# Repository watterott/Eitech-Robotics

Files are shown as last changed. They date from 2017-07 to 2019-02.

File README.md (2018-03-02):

# Eitech Robotics
Eitech Robotics is an Microchip SAMW25 based open-source robotics board.

* [Microchip ATSAMW25](http://www.microchip.com/wwwproducts/en/ATSAMW25) Module (SAM D21 ARM Cortex-M0+ and WINC1500 WiFi/WLAN SoC)
* USB CDC+MSC Bootloader (Arduino compatible)
* 5V tolerant IOs, UART, SPI, I2C
* 2x Dual Full-Bridge Motor Drivers (Allegro Micro A3909, up to 1A per Phase)
* 5V Switching Regulator (up to 2A)

## Hardware and Software
* [Schematics/Layout](https://github.com/watterott/Eitech-Robotics/tree/master/hardware)
* [Board Support Package for Arduino IDE](https://github.com/watterott/Eitech-Robotics/tree/master/arduino#eitech-board-support-package)
* [Driver for Windows](https://github.com/watterott/Eitech-Robotics/raw/master/arduino/driver.zip)

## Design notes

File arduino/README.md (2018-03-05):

# Eitech Board Support Package
Board Support Package for [Arduino IDE v1.8+](https://www.arduino.cc/en/Main/Software).

## Installation

Add the following URL to the Arduino Boards Manager (*File->Preferences*):
```
https://github.com/watterott/Eitech-Robotics/raw/master/arduino/package_eitech_index.json
```
Then open the Arduino Boards Manager (*Tools->Boards->Boards Manager*) and install the 
**Arduino SAMD Boards** and **Eitech SAMD Boards**.

## Bootloader

The bootloader can be activated via the Arduino IDE or by doing two reset in 0.5s (double pressing reset switch).

When the bootloader is active then a new program can be loaded via the Arduino IDE and the serial port or via the mass storage device.
For the mass storage device just copy a new binary file (.bin) to the drive.

On Linux/Mac the dd command can be used to write the firmware: ```dd if=APP.BIN of=/media/ROBOTICS/APP.BIN conv=notrunc```

A binary file can be generated and exported in the Arduino IDE with *Sketch->Export compiled Binary* command.

## Known Issues

### Windows
Sometimes the driver for the USB Bootloader is not loaded correctly.
Check the driver state in the Device Manager, when the Bootloader is active (double press reset).
If you cannot install the driver on Windows 8 or higher then deactivate the [driver signature enforcement](https://learn.sparkfun.com/tutorials/disabling-driver-signature-on-windows-8/disabling-signed-driver-enforcement-on-windows-8).
* [Eitech Robotics Driver](https://github.com/watterott/Eitech-Robotics/raw/master/arduino/driver.zip)

### Linux
The Modem Manager detects the Serial Ports (e.g. the USB Bootloader) as a modem and therefore a blacklist rule is needed.
Run one of the commands - depending on your system:

```sudo nano /etc/udev/rules.d/77-mm-usb-device-blacklist.rules```

```sudo nano /lib/udev/rules.d/77-mm-usb-device-blacklist.rules```

and add the following lines to the file:
```
ATTRS{idVendor}=="1D50", ATTRS{idProduct}=="6110", ENV{ID_MM_DEVICE_IGNORE}="1"
ATTRS{idVendor}=="1D50", ATTRS{idProduct}=="6111", ENV{ID_MM_DEVICE_IGNORE}="1"
```

Reload udev rules:
```
sudo udevadm control --reload-rules
```

Or you can also remove the Modem Manager from your system with
```
sudo apt-get uninstall modemmanager
```

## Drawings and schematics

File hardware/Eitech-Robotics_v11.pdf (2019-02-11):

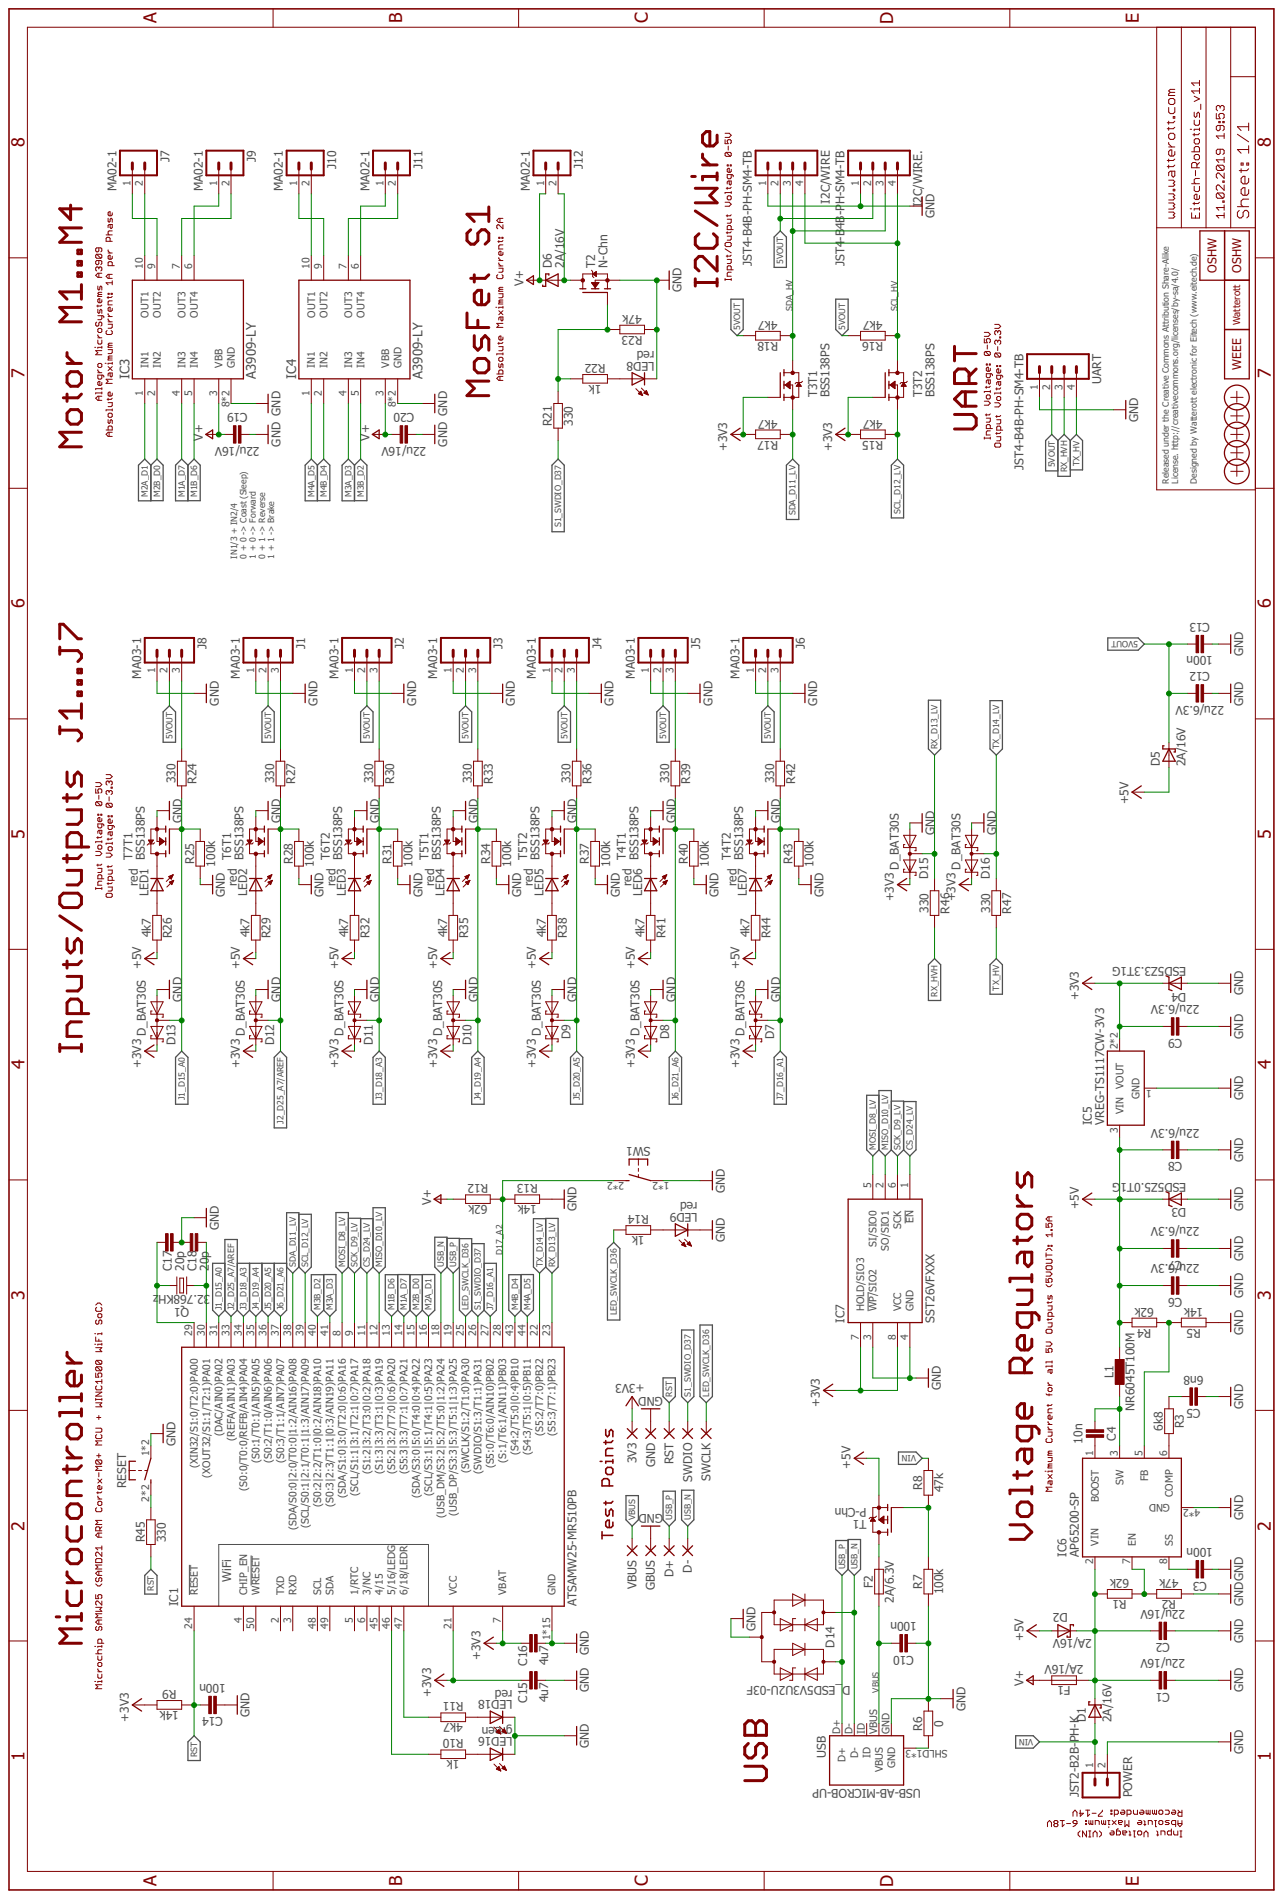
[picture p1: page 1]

Released under the Creative Commons Attribution Share-Alike

License. http://creativecommons.org/licenses/by-sa/4.0/ Designed by Watterott electronic for Eitech (www.eitech.de)

GND GND GND GND GND

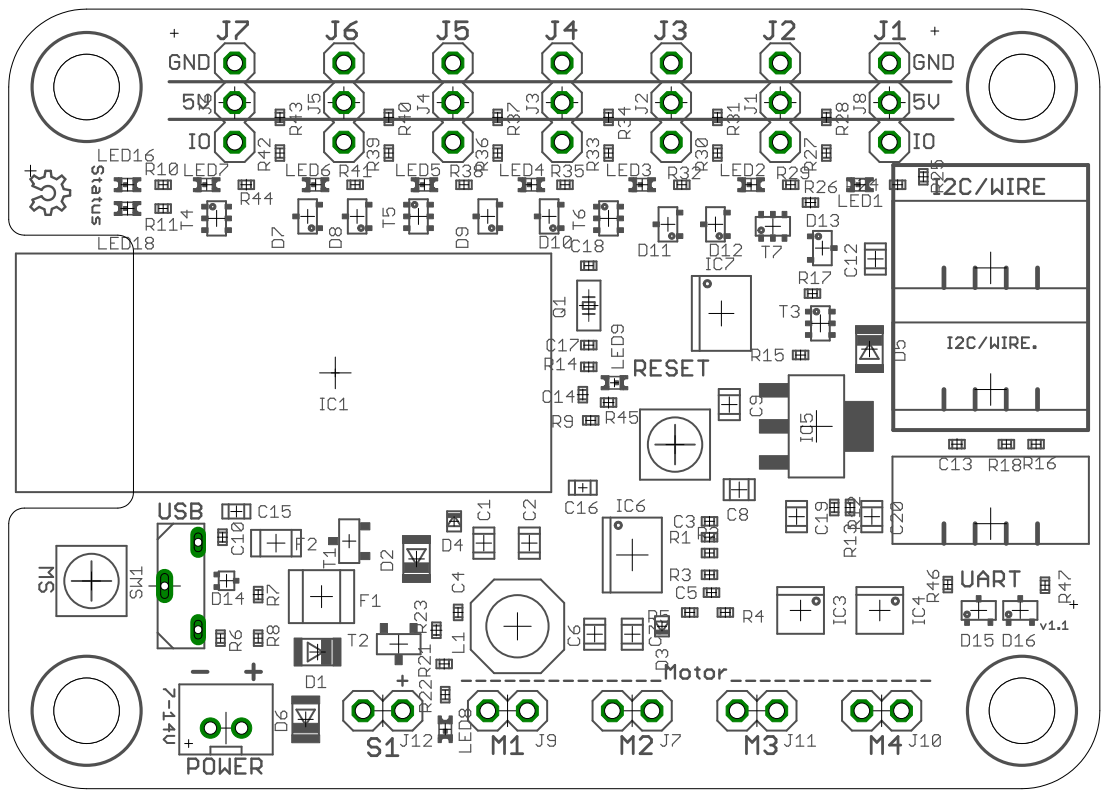
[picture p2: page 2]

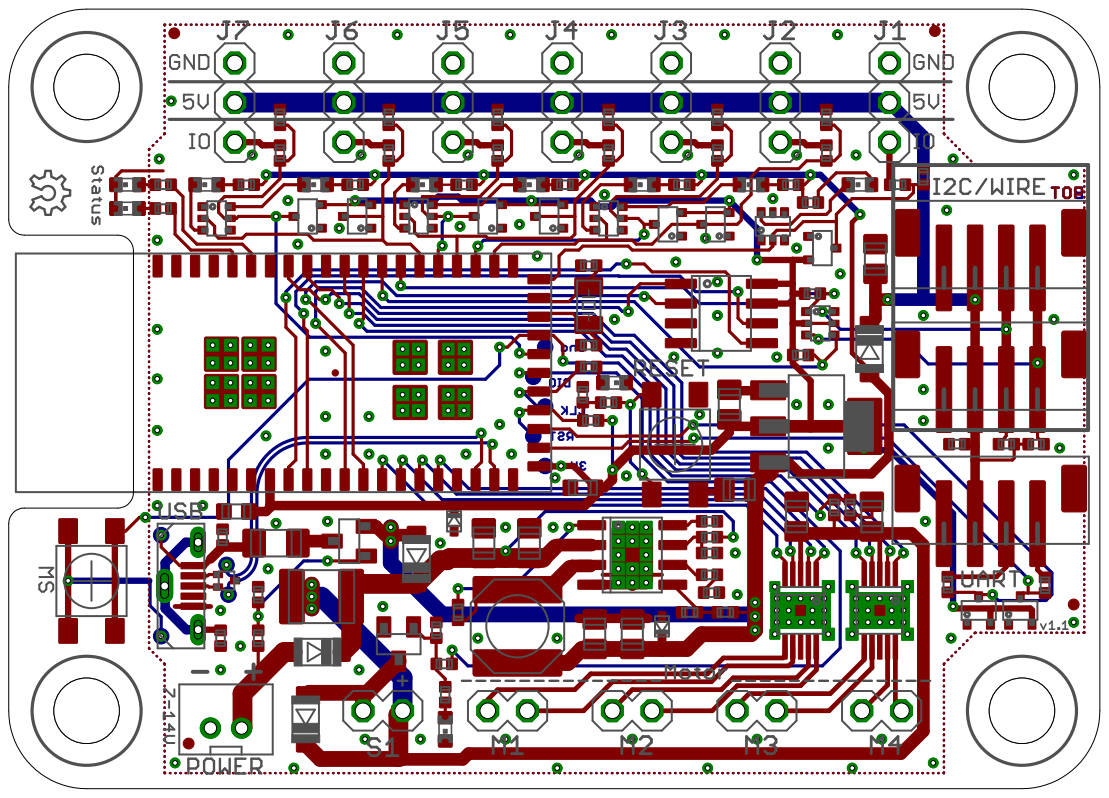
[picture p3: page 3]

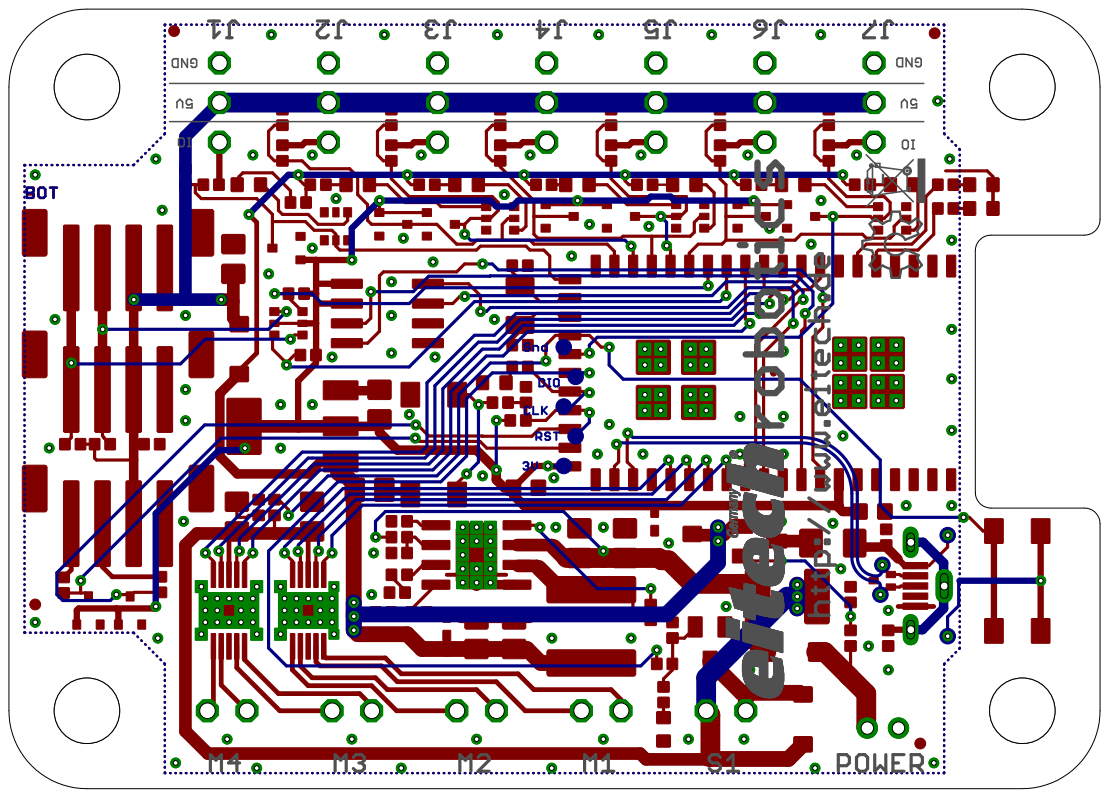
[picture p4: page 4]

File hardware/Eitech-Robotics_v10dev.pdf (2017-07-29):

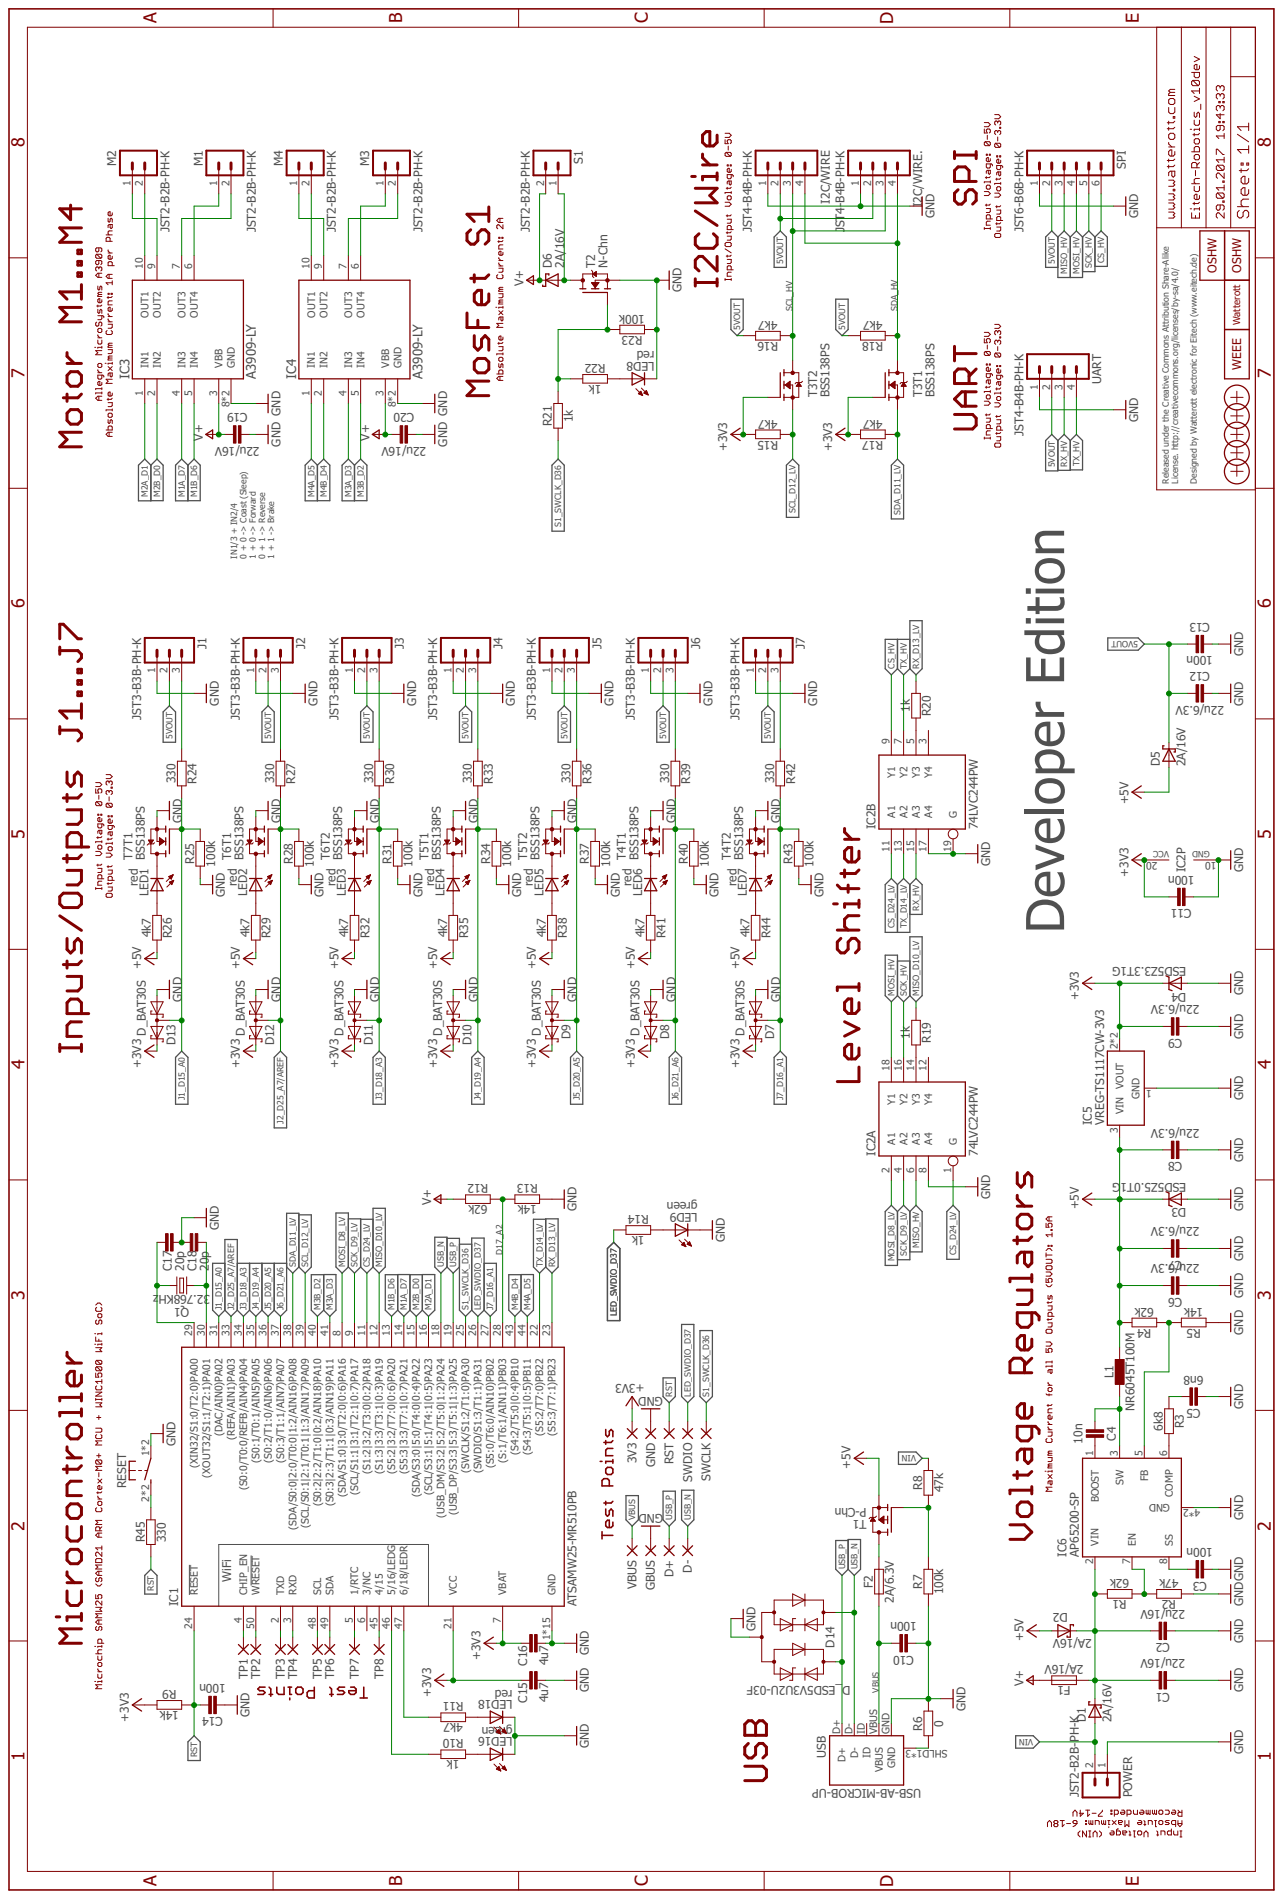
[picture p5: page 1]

License. ht p://creativecommons.org/licenses/by-sa/4.0/ Designed by Wat erot electronic for Eitech (www.eitech.de) D

Released under the Creative Commons At ribution Share-Alike

GND GND GND GND GND

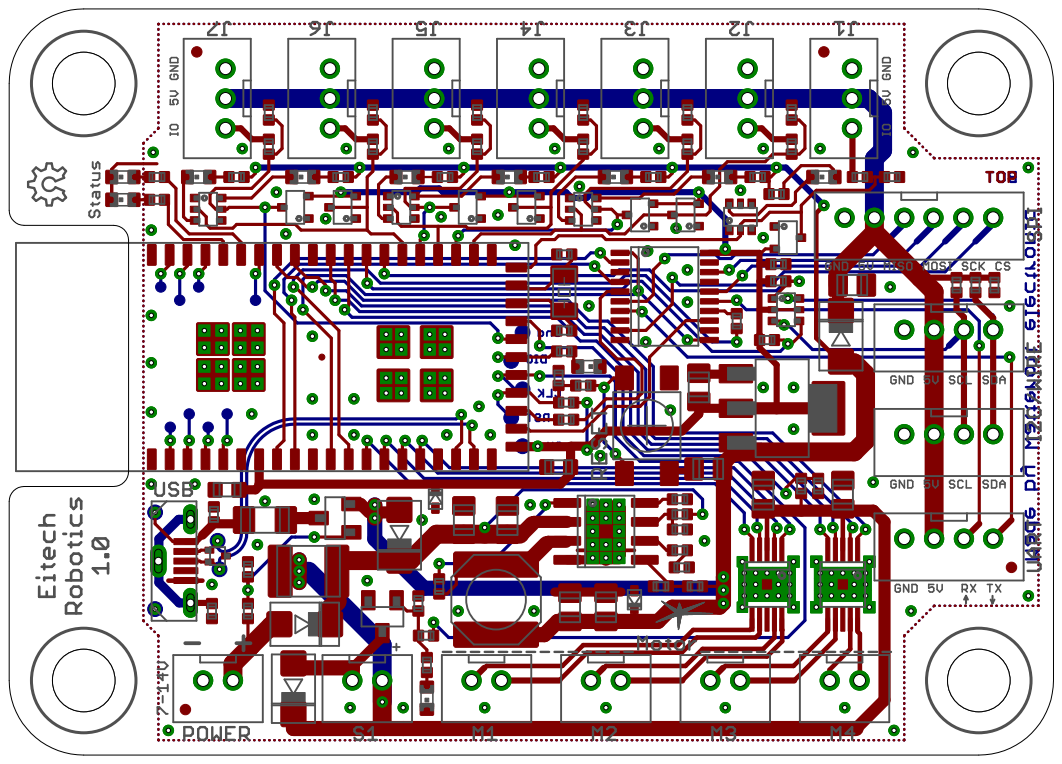
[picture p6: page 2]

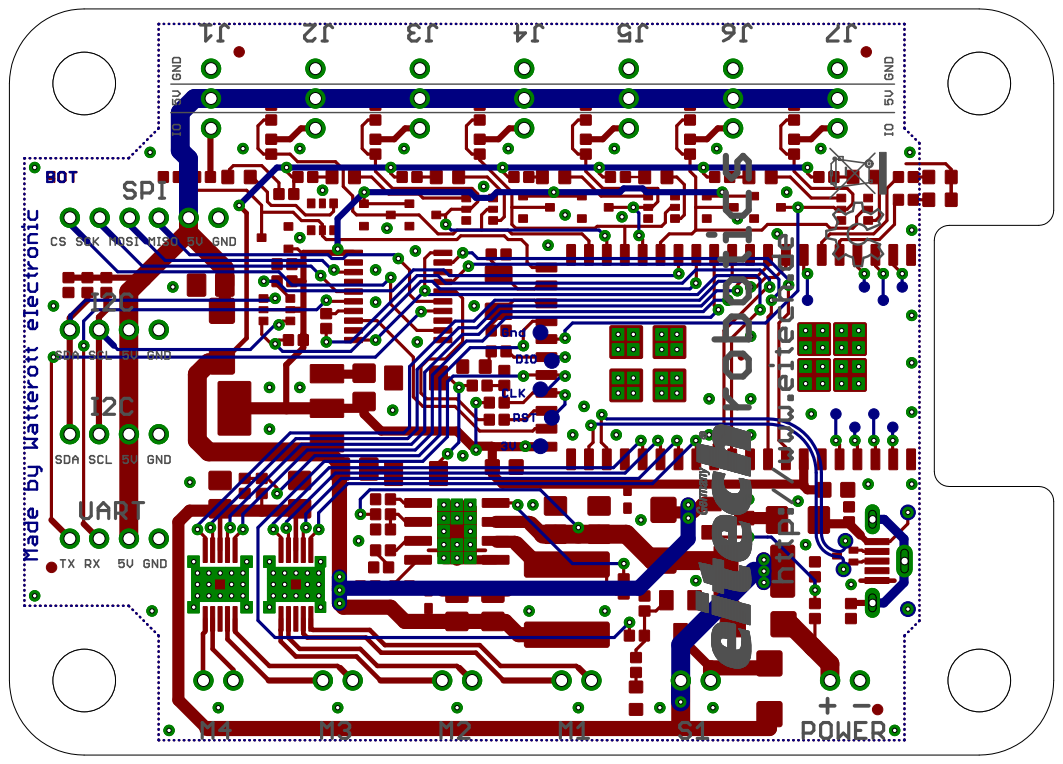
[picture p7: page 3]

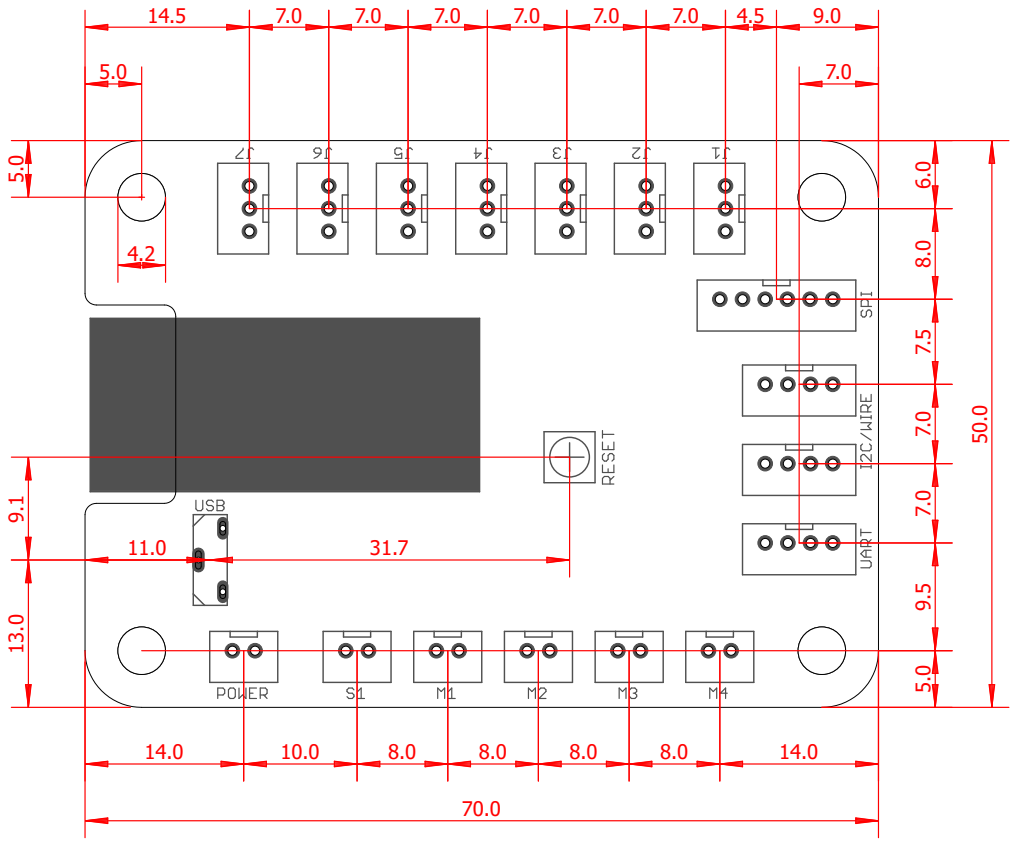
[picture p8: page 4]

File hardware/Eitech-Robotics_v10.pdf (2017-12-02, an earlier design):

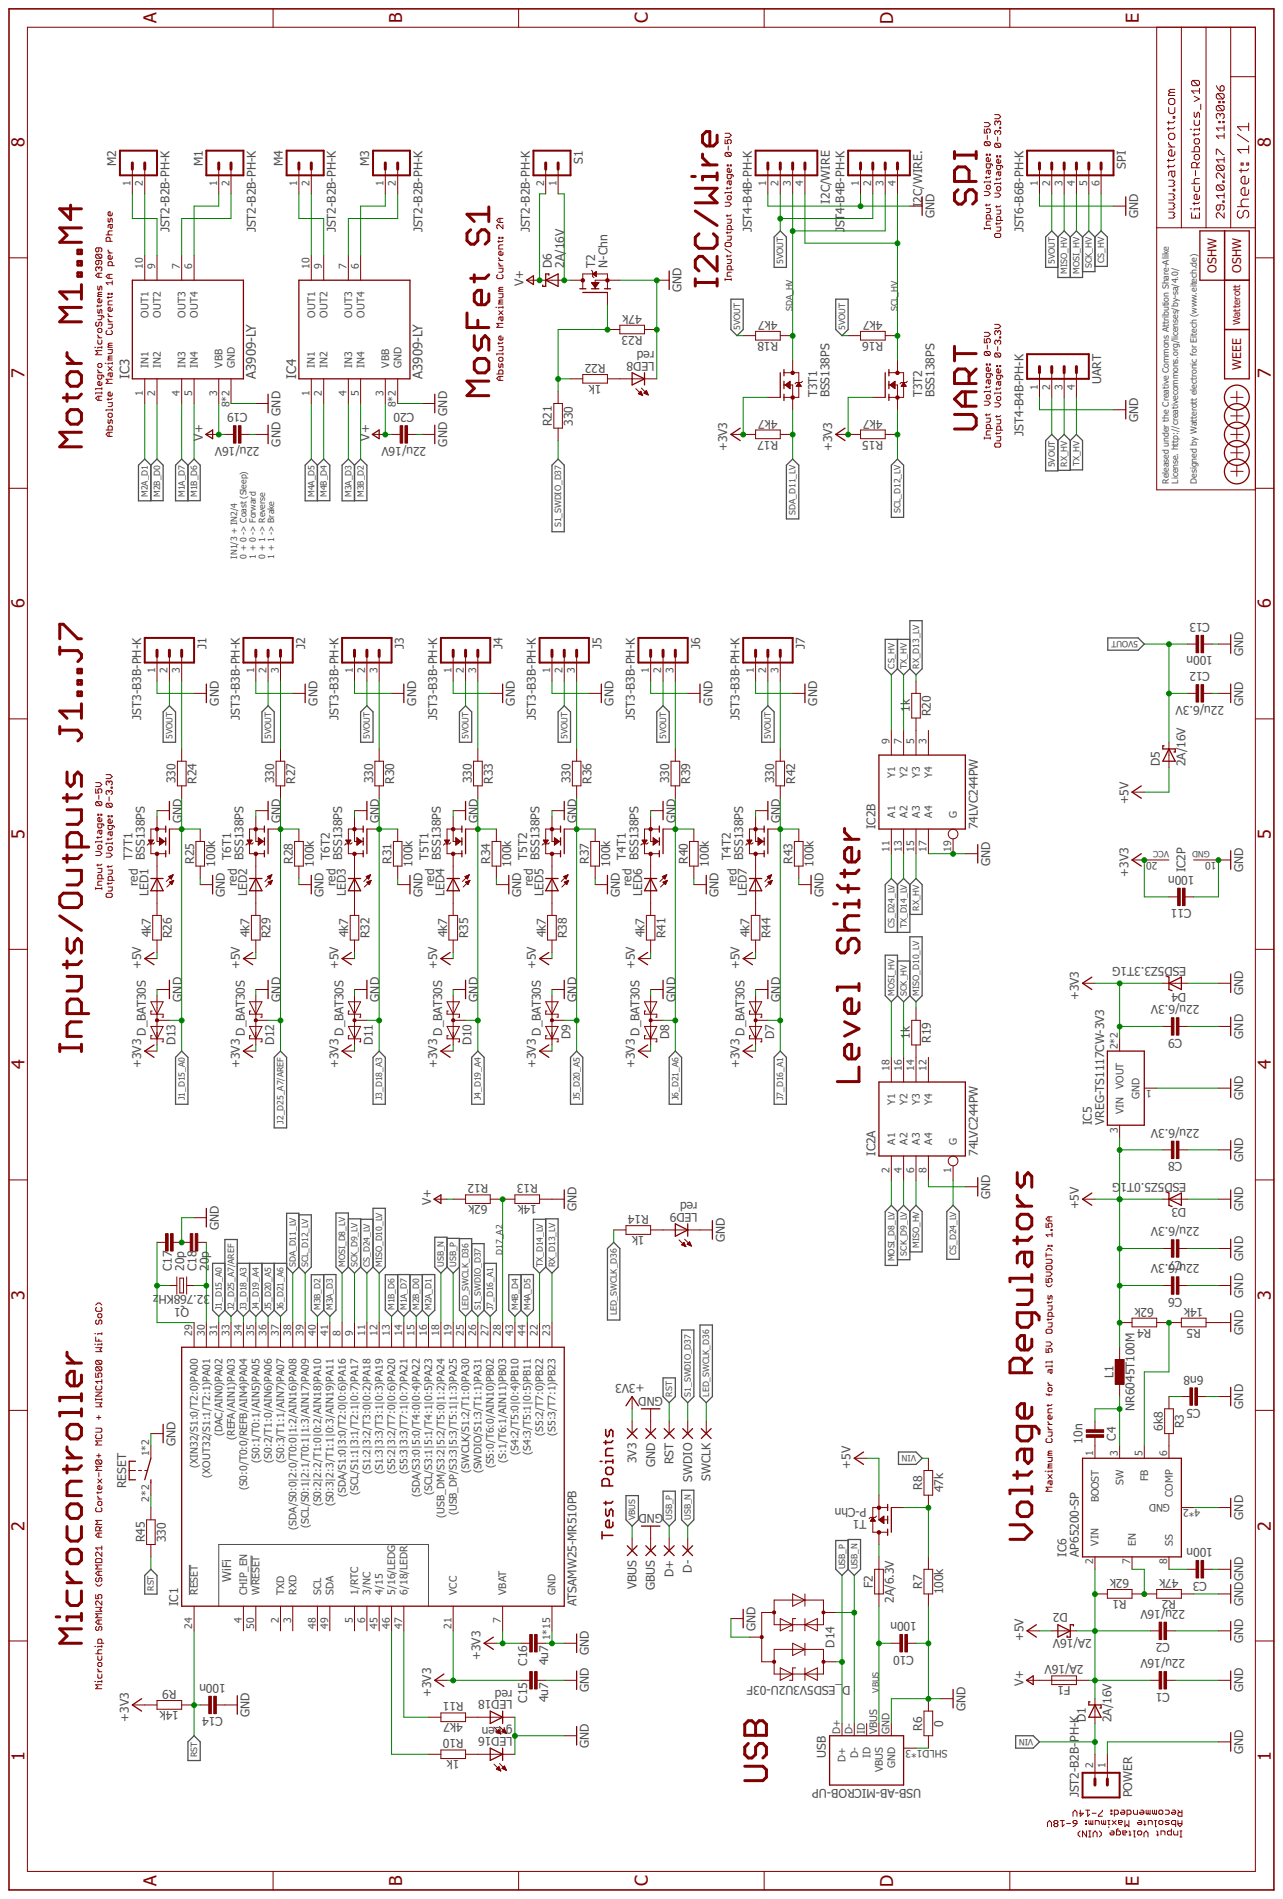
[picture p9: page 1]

Released under the Creative Commons At ribution Share-Alike

License. ht p://creativecommons.org/licenses/by-sa/4.0/ Designed by Wat erot electronic for Eitech (www.eitech.de)

GND GND GND GND GND

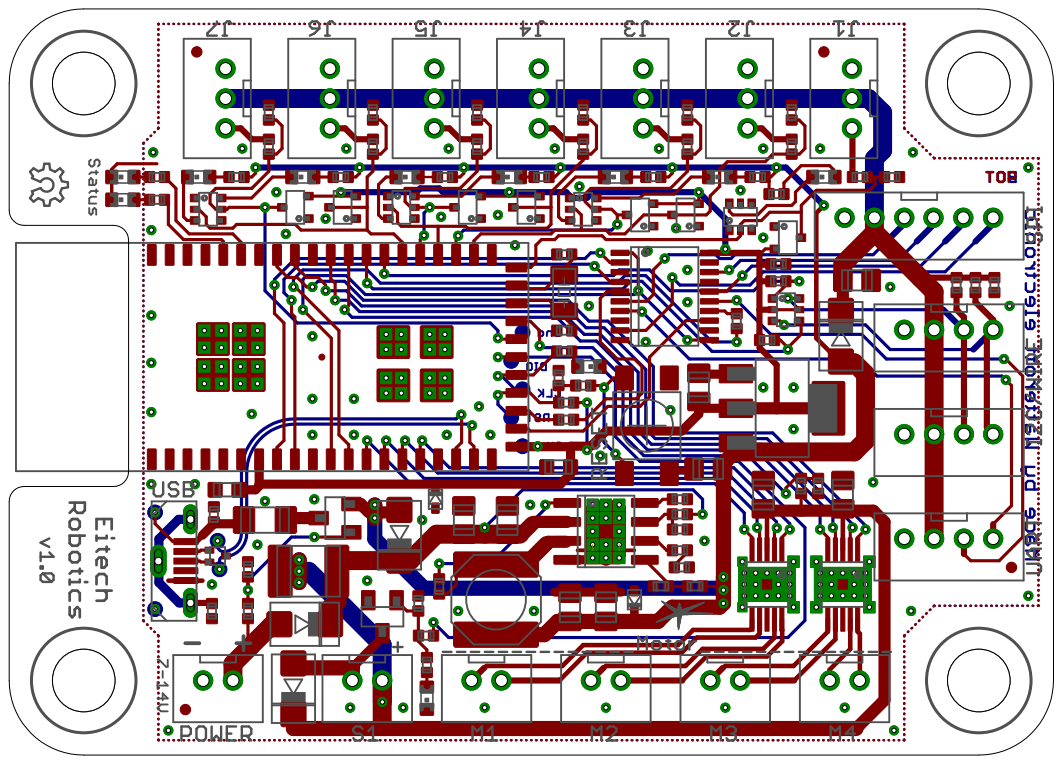
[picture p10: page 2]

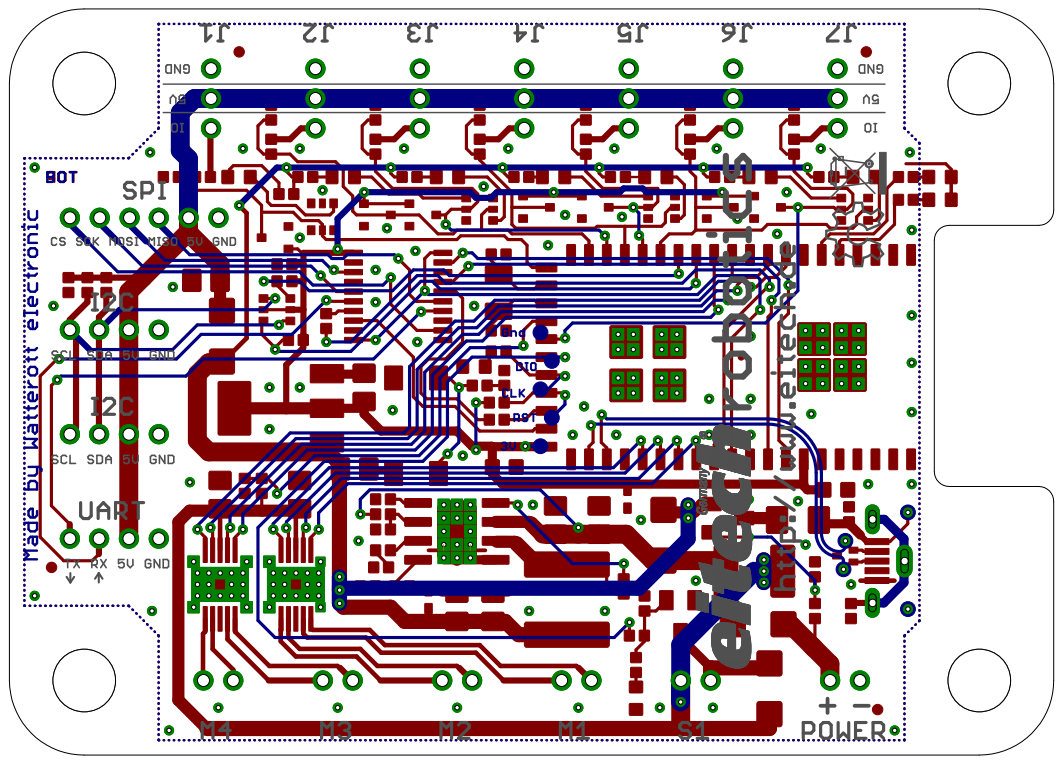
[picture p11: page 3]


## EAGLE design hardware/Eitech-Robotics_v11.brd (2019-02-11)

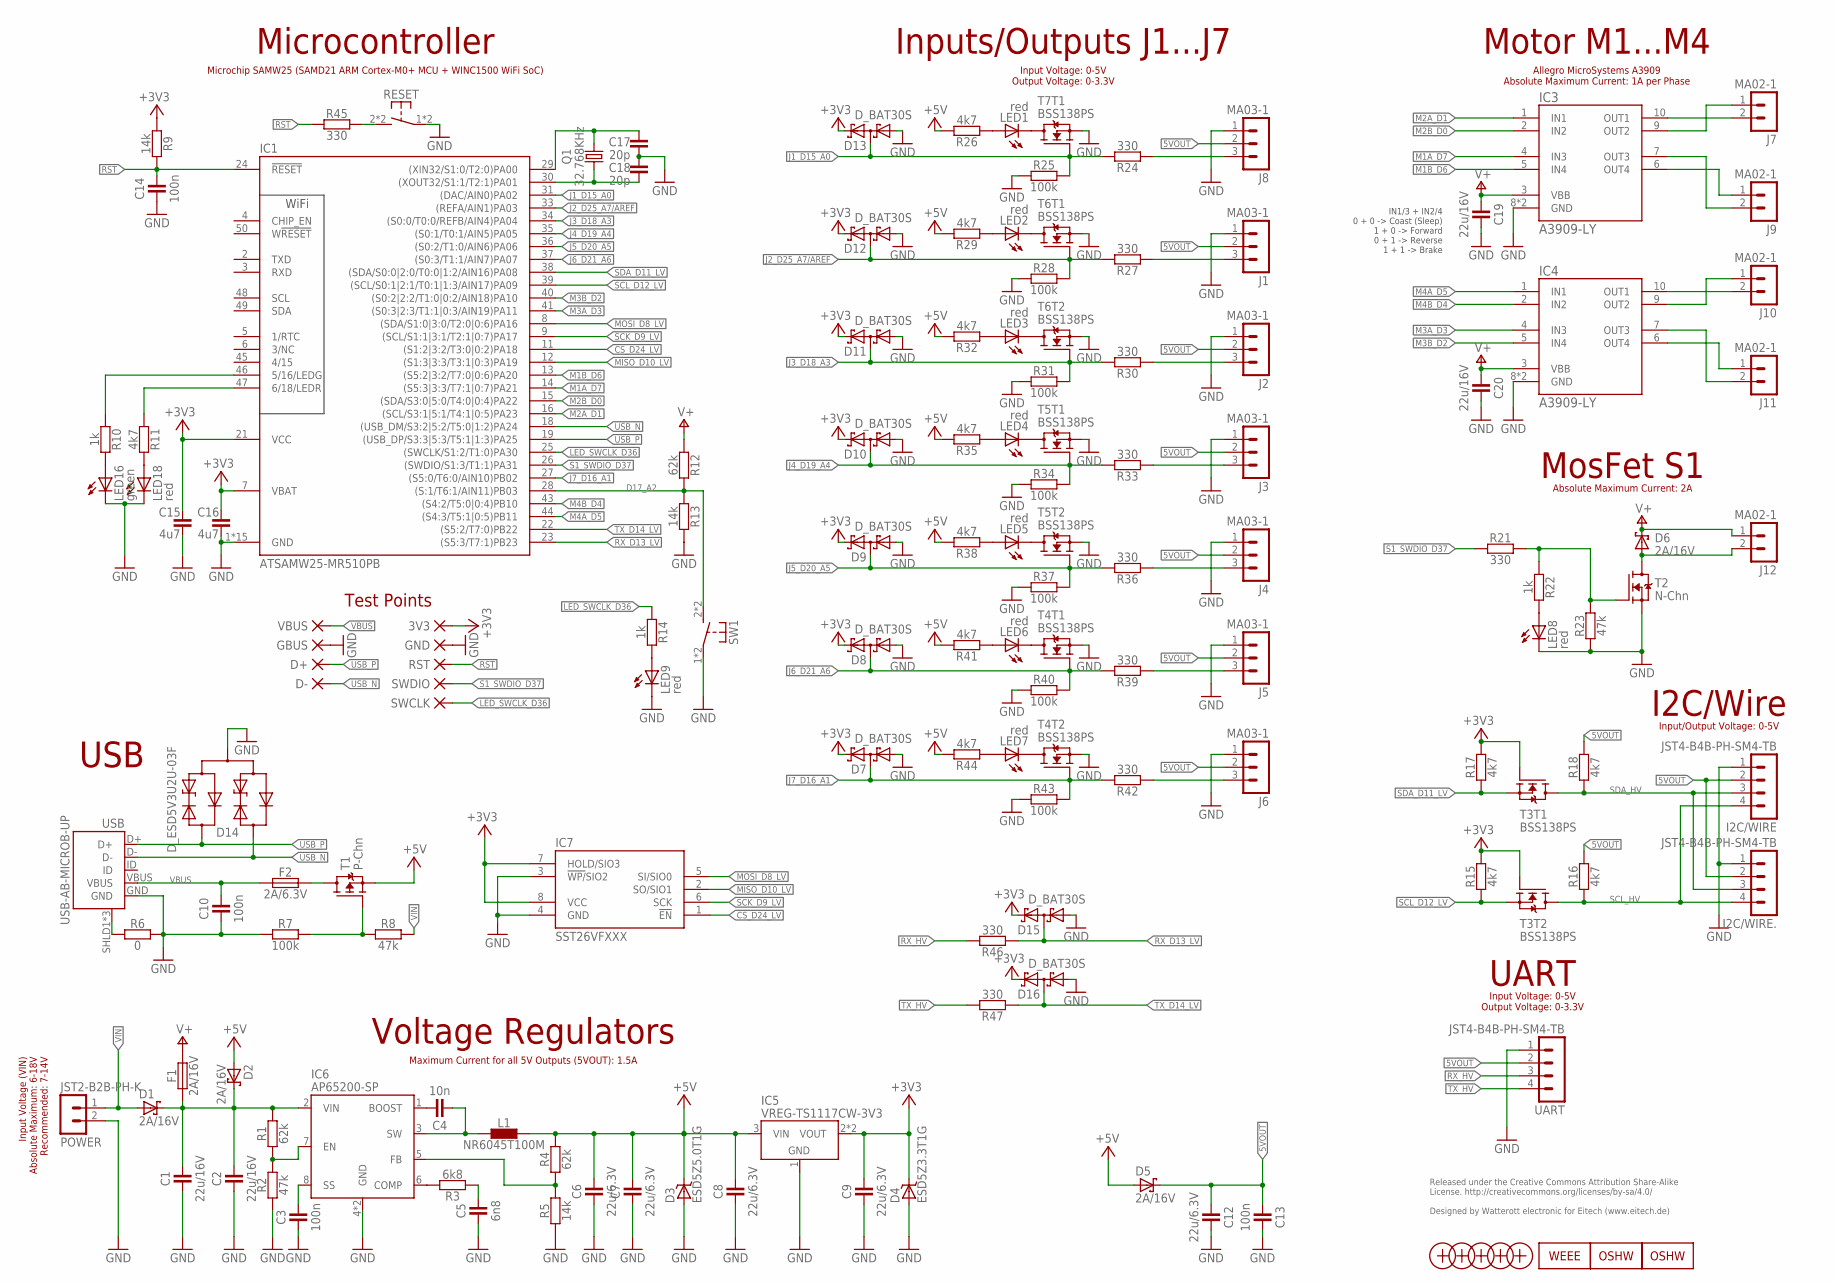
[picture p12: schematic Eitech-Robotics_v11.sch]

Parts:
3V3: PAD-1.0_NC
C1, C2, C19, C20: 22u/16V; C0805
C3, C10, C13, C14: 100n; C0402
C4: 10n; C0402
C5: 6n8; C0402
C6, C7, C8, C9, C12: 22u/6.3V; C0805
C15, C16: 4u7; C0603
C17, C18: 20p; C0402
D1, D2, D5, D6: 2A/16V; SOD123
D3: ESD5Z5.0T1G; SOD523
D4: ESD5Z3.3T1G; SOD523
D7, D8, D9, D10, D11, D12, D13, D15, D16: D_BAT30S; SOT323
D14: D_ESD5V3U2U-03F; SOT723
D+: PAD-1.0_NC
D-: PAD-1.0_NC
F1: 2A/16V; C1812
F2: 2A/6.3V; C1206
GBUS: PAD-1.0_NC
GND: PAD-1.0_NC
I2C/WIRE, I2C/WIRE.: JST4-B4B-PH-SM4-TB; JST_B4B-PH-SM4-TB
IC1: ATSAMW25-MR510PB; ATSAMW25-MRX10
IC3, IC4: A3909-LY; MSOP10-PAD
IC5: VREG-TS1117CW-3V3; SOT223
IC6: AP65200-SP; SO08-PAD
IC7: SST26VFXXX; SO08
J1, J2, J3, J4, J5, J6, J8: MA03-1
J7, J9, J10, J11, J12: MA02-1
L1: NR6045T100M; L_NR60XX
LED1, LED2, LED3, LED4, LED5, LED6, LED7, LED8, LED9, LED18: red; C0603
LED16: green; C0603
LOGO1: OSHW_LOGOX0100; OSHW_6X100
LOGO2: OSHW_LOGOX0150; OSHW_6X150
LOGO4: WEEE_LOGO-S; WEEE_TPLAC_S
POWER: JST2-B2B-PH-K; JST_B2B-PH-K
Q1: 32.768KHz; CRYSTAL_ZM315
R1, R4, R12: 62k; C0402
R2, R8, R23: 47k; C0402
R3: 6k8; C0402
R5, R9, R13: 14k; C0402
R6: 0; C0402
R7, R25, R28, R31, R34, R37, R40, R43: 100k; C0402
R10, R14, R22: 1k; C0402
R11, R15, R16, R17, R18, R26, R29, R32, R35, R38, R41, R44: 4k7; C0402
R21, R24, R27, R30, R33, R36, R39, R42, R45, R46, R47: 330; C0402
RESET: SW-TACTILE-TL3305C; TL3305; MPN TL3305C
RST: PAD-1.0_NC
SW1: SW-TACTILE-TL3305C; TL3305; MPN TL3305C
SWCLK: PAD-1.0_NC
SWDIO: PAD-1.0_NC
T1: P-Chn; SOT23
T2: N-Chn; SOT23
T3, T4, T5, T6, T7: BSS138PS; SOT363
UART: JST4-B4B-PH-SM4-TB; JST_B4B-PH-SM4-TB
USB: USB-AB-MICROB-UP; USB-MICROB-1051330011
VBUS: PAD-1.0_NC
X1, X2, X3, X4: PASSER-07; PASSER_07MM
X5: PASSER-04; PASSER_04MM

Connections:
5VOUT: C12.2, C13.2, D5.C, I2C/WIRE.2, I2C/WIRE..2, J1.2, J2.2, J3.2, J4.2, J5.2, J6.2, J8.2, R16.2, R18.2, UART.2
+3V3: 3V3.1, C9.2, C15.2, C16.2, D4.C, D7.2 (C), D8.2 (C), D9.2 (C), D10.2 (C), D11.2 (C), D12.2 (C), D13.2 (C), D15.2 (C), D16.2 (C), IC1.7 (VBAT), IC1.21 (VCC), IC5.2 (VOUT), IC5.4 (VOUT), IC7.7 (HOLD/SIO3), IC7.8 (VCC), R9.1, R15.2, R17.2, T3.2 (G), T3.5 (G)
+5V: C6.2, C7.2, C8.2, D2.A, D3.C, D5.A, IC5.3 (VIN), L1.2, R4.2, R26.2, R29.2, R32.2, R35.2, R38.2, R41.2, R44.2, T1.2 (S)
BOOST: C4.2, IC6.1 (BOOST)
COMP: IC6.6 (COMP), R3.2
CS_D24_LV: IC1.11 ((S1:2|3:2/T3:0|0:2)PA18), IC7.1 (!EN)
D17_A2: IC1.28 ((S:1/T6:1/AIN11)PB03), R12.2, R13.1, SW1.2 (S1), SW1.3 (S1)
GND: C1.1, C2.1, C3.1, C5.1, C6.1, C7.1, C8.1, C9.1, C10.1, C12.1, C13.1, C14.1, C15.1, C16.1, C17.2, C18.2, C19.2, C20.2, D3.A, D4.A, D7.1 (A), D8.1 (A), D9.1 (A), D10.1 (A), D11.1 (A), D12.1 (A), D13.1 (A), D14.3 (A), D15.1 (A), D16.1 (A), GBUS.1, GND.1, I2C/WIRE.1, I2C/WIRE..1, IC1.1 (GND), IC1.10 (GND), IC1.17 (GND), IC1.20 (GND), IC1.32 (GND), IC1.42 (GND), IC1.51 (GND), IC1.GND@1 (GND), IC1.GND@2 (GND), IC1.GND@3 (GND), IC1.GND@4 (GND), IC1.GND@5 (GND), IC1.GND@6 (GND), IC1.GND@7 (GND), IC1.GND@8 (GND), IC3.8 (GND), IC3.TP (GND), IC4.8 (GND), IC4.TP (GND), IC5.1 (GND), IC6.4 (GND), IC6.TP (GND), IC7.3 (!WP/!SIO2), IC7.4 (GND), J1.1, J2.1, J3.1, J4.1, J5.1, J6.1, J8.1, LED8.C, LED9.C, LED16.C, LED18.C, POWER.2, R2.1, R5.1, R6.1, R7.1, R13.2, R23.1, R25.1, R28.1, R31.1, R34.1, R37.1, R40.1, R43.1, RESET.1, RESET.4 (P1), SW1.1, SW1.4 (P1), T2.2 (S), T4.1 (S), T4.4 (S), T5.1 (S), T5.4 (S), T6.1 (S), T6.4 (S), T7.1 (S), UART.1, USB.GND
IO16: IC1.46 (5/16/LEDG), R10.1
IO18: IC1.47 (6/18/LEDR), R11.1
J1_D15_A0: D13.3 (CA), IC1.31 ((DAC/AIN0)PA02), R24.2, R25.2, T7.2 (G)
J2_D25_A7/AREF: D12.3 (CA), IC1.33 ((REFA/AIN1)PA03), R27.2, R28.2, T6.2 (G)
J3_D18_A3: D11.3 (CA), IC1.34 ((S0:0/T0:0/REFB/AIN4)PA04), R30.2, R31.2, T6.5 (G)
J4_D19_A4: D10.3 (CA), IC1.35 ((S0:1/T0:1/AIN5)PA05), R33.2, R34.2, T5.2 (G)
J5_D20_A5: D9.3 (CA), IC1.36 ((S0:2/T1:0/AIN6)PA06), R36.2, R37.2, T5.5 (G)
J6_D21_A6: D8.3 (CA), IC1.37 ((S0:3/T1:1/AIN7)PA07), R39.2, R40.2, T4.2 (G)
J7_D16_A1: D7.3 (CA), IC1.27 ((S5:0/T6:0/AIN10)PB02), R42.2, R43.2, T4.5 (G)
LED_SWCLK_D36: IC1.25 ((SWCLK/S1:2/T1:0)PA30), R14.1, SWCLK.1
M1A_D7: IC1.14 ((S5:3|3:3/T7:1|0:7)PA21), IC3.4 (IN3)
M1B_D6: IC1.13 ((S5:2|3:2/T7:0|0:6)PA20), IC3.5 (IN4)
M1_O1: IC3.7 (OUT3), J9.2
M1_O2: IC3.6 (OUT4), J9.1
M2A_D1: IC1.16 ((SCL/S3:1|5:1/T4:1|0:5)PA23), IC3.1 (IN1)
M2B_D0: IC1.15 ((SDA/S3:0|5:0/T4:0|0:4)PA22), IC3.2 (IN2)
M2_O1: IC3.10 (OUT1), J7.2
M2_O2: IC3.9 (OUT2), J7.1
M3A_D3: IC1.41 ((S0:3|2:3/T1:1|0:3/AIN19)PA11), IC4.4 (IN3)
M3B_D2: IC1.40 ((S0:2|2:2/T1:0|0:2/AIN18)PA10), IC4.5 (IN4)
M3_O1: IC4.7 (OUT3), J11.2
M3_O2: IC4.6 (OUT4), J11.1
M4A_D5: IC1.44 ((S4:3/T5:1|0:5)PB11), IC4.1 (IN1)
M4B_D4: IC1.43 ((S4:2/T5:0|0:4)PB10), IC4.2 (IN2)
M4_O1: IC4.10 (OUT1), J10.2
M4_O2: IC4.9 (OUT2), J10.1
MISO_D10_LV: IC1.12 ((S1:3|3:3/T3:1|0:3)PA19), IC7.2 (SO/SIO1)
MOSI_D8_LV: IC1.8 ((SDA/S1:0|3:0/T2:0|0:6)PA16), IC7.5 (SI/SIO0)
unnamed: LED8.A, R22.2
unnamed: J8.3, R24.1
unnamed: F2.2, T1.3 (D)
unnamed: R7.2, R8.1, T1.1 (G)
unnamed: LED9.A, R14.2
unnamed: R21.2, R22.1, R23.2, T2.1 (G)
unnamed: LED7.C, T4.3 (D)
unnamed: LED7.A, R44.1
unnamed: J6.3, R42.1
unnamed: C4.1, IC6.3 (SW), L1.1
unnamed: C3.2, IC6.8 (SS)
unnamed: J5.3, R39.1
unnamed: J4.3, R36.1
unnamed: J3.3, R33.1
unnamed: IC6.5 (FB), R4.1, R5.2
unnamed: LED6.C, T4.6 (D)
unnamed: LED6.A, R41.1
unnamed: J1.3, R27.1
unnamed: LED5.A, R38.1
unnamed: J2.3, R30.1
unnamed: LED4.A, R35.1
unnamed: LED4.C, T5.6 (D)
unnamed: LED5.C, T5.3 (D)
unnamed: LED3.A, R32.1
unnamed: LED2.A, R29.1
unnamed: LED2.C, T6.6 (D)
unnamed: LED3.C, T6.3 (D)
unnamed: LED1.A, R26.1
unnamed: LED1.C, T7.6 (D)
unnamed: C5.2, R3.1
unnamed: IC6.7 (EN), R1.1, R2.2
unnamed: LED18.A, R11.2
unnamed: LED16.A, R10.2
RST: C14.2, IC1.24 (!RESET), R9.2, R45.1, RST.1
RST_SW: R45.2, RESET.2 (S1), RESET.3 (S1)
RX_D13_LV: D15.3 (CA), IC1.23 ((S5:3/T7:1)PB23), R46.1
RX_HV: R46.2, UART.3
S1: D6.A, J12.2, T2.3 (D)
S1_SWDIO_D37: IC1.26 ((SWDIO/S1:3/T1:1)PA31), R21.1, SWDIO.1
SCK_D9_LV: IC1.9 ((SCL/S1:1|3:1/T2:1|0:7)PA17), IC7.6 (SCK)
SCL_D12_LV: IC1.39 ((SCL/S0:1|2:1/T0:1|1:3/AIN17)PA09), R15.1, T3.4 (S)
SCL_HV: I2C/WIRE.4, I2C/WIRE..4, R16.1, T3.3 (D)
SDA_D11_LV: IC1.38 ((SDA/S0:0|2:0/T0:0|1:2/AIN16)PA08), R17.1, T3.1 (S)
SDA_HV: I2C/WIRE.3, I2C/WIRE..3, R18.1, T3.6 (D)
SHLD1: R6.2, USB.SHLD1 (SHIELD), USB.SHLD2 (SHIELD), USB.SHLD3 (SHIELD)
TX_D14_LV: D16.3 (CA), IC1.22 ((S5:2/T7:0)PB22), R47.1
TX_HV: R47.2, UART.4
USB_N: D14.1 (C1), D-.1, IC1.18 ((USB_DM/S3:2|5:2/T5:0|1:2)PA24), USB.D-
USB_P: D14.2 (C2), D+.1, IC1.19 ((USB_DP/S3:3|5:3/T5:1|1:3)PA25), USB.D+
V+: C19.1, C20.1, D6.C, F1.2, IC3.3 (VBB), IC4.3 (VBB), J12.1, R12.1
VBUS: C10.2, F2.1, USB.VBUS, VBUS.1
VIN: D1.A, POWER.1, R8.2
VINP: C1.2, C2.2, D1.C, D2.C, F1.1, IC6.2 (VIN), R1.2
XIN: C17.1, IC1.29 ((XIN32/S1:0/T2:0)PA00), Q1.2
XOUT: C18.1, IC1.30 ((XOUT32/S1:1/T2:1)PA01), Q1.1

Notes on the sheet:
USB
Motor M1...M4
MosFet S1
I2C/Wire
UART
Inputs/Outputs J1...J7
Voltage Regulators
Microcontroller
Test Points
Released under the Creative Commons Attribution Share-Alike License. http://creativecommons.org/licenses/by-sa/4.0/ Designed by Watterott electronic for Eitech (www.eitech.de)
Input Voltage (VIN) Absolute Maximum: 6-18V Recommended: 7-14V
Input Voltage: 0-5V Output Voltage: 0-3.3V
Allegro MicroSystems A3909 Absolute Maximum Current: 1A per Phase
Input/Output Voltage: 0-5V
Absolute Maximum Current: 2A
Microchip SAMW25 (SAMD21 ARM Cortex-M0+ MCU + WINC1500 WiFi SoC)
Maximum Current for all 5V Outputs (5VOUT): 1.5A
IN1/3 + IN2/4 0 + 0 -> Coast (Sleep) 1 + 0 -> Forward 0 + 1 -> Reverse 1 + 1 -> Brake

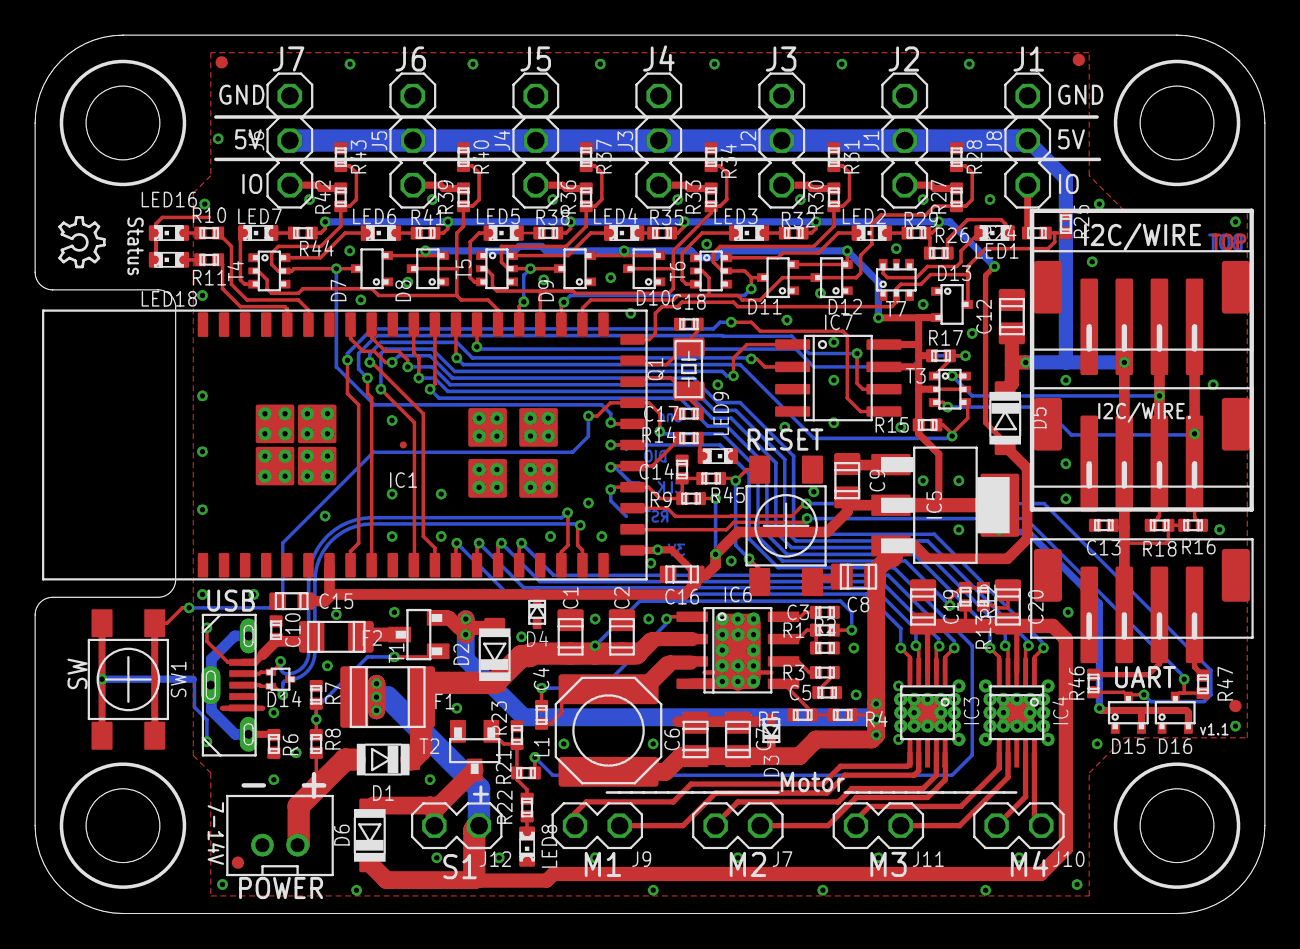
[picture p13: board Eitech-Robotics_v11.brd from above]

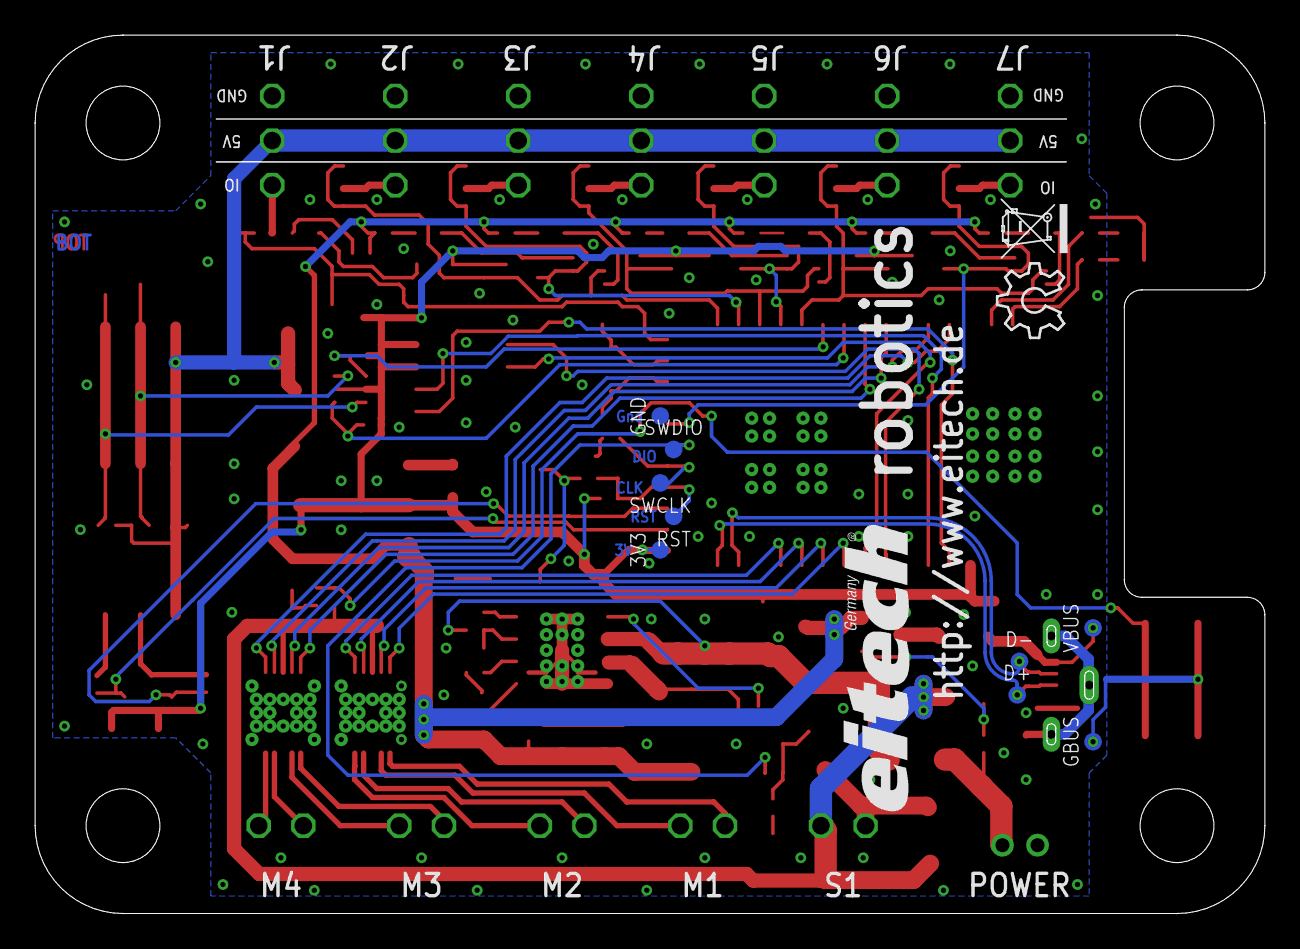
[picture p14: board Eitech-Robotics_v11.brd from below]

Board: 2 copper layers, 70.0 x 50.0 mm, 144 parts (11 on the bottom side), 91 nets.

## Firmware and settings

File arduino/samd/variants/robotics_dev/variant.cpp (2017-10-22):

/*
  Copyright (c) 2014-2015 Arduino LLC.  All right reserved.

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
  You should have received a copy of the GNU Lesser General Public
  License along with this library; if not, write to the Free Software
  Foundation, Inc., 51 Franklin St, Fifth Floor, Boston, MA  02110-1301  USA
*/

#include "variant.h"

const PinDescription g_APinDescription[] = {

/*
 +------------+------------------+--------+-----------------+--------+-----------------------+---------+---------+--------+--------+----------+----------+
 | Pin number |  MKR  Board pin  |  PIN   | Notes           | Peri.A |     Peripheral B      | Perip.C | Perip.D | Peri.E | Peri.F | Periph.G | Periph.H |
 |            |                  |        |                 |   EIC  | ADC |  AC | PTC | DAC | SERCOMx | SERCOMx |  TCCx  |  TCCx  |    COM   | AC/GLCK  |
 |            |                  |        |                 |(EXTINT)|(AIN)|(AIN)|     |     | (x/PAD) | (x/PAD) | (x/WO) | (x/WO) |          |          |
 +------------+------------------+--------+-----------------+--------+-----+-----+-----+-----+---------+---------+--------+--------+----------+----------+
 | 00         | D0               |  PA22  |                 |  *06   |     |     | X10 |     |   3/00  |   5/00  |* TC4/0 | TCC0/4 |          | GCLK_IO6 |
 | 01         | D1               |  PA23  |                 |  *07   |     |     | X11 |     |   3/01  |   5/01  |* TC4/1 | TCC0/5 | USB/SOF  | GCLK_IO7 |
 | 02         | D2               |  PA10  |                 |   10   | *18 |     | X02 |     |   0/02  |   2/02  |*TCC1/0 | TCC0/2 | I2S/SCK0 | GCLK_IO4 |
 | 03         | D3               |  PA11  |                 |   11   | *19 |     | X03 |     |   0/03  |   2/03  |*TCC1/1 | TCC0/3 | I2S/FS0  | GCLK_IO5 |
 | 04         | D4               |  PB10  |                 |  *10   |     |     |     |     |         |   4/02  |* TC5/0 | TCC0/4 | I2S/MCK1 | GCLK_IO4 |
 | 05         | D5               |  PB11  |                 |  *11   |     |     |     |     |         |   4/03  |* TC5/1 | TCC0/5 | I2S/SCK1 | GCLK_IO5 |
 | 06         | D6               |  PA20  |                 |  *04   |     |     | X08 |     |   5/02  |   3/02  |        |*TCC0/6 | I2S/SCK0 | GCLK_IO4 |
 | 07         | D7               |  PA21  |                 |  *05   |     |     | X09 |     |   5/03  |   3/03  |        |*TCC0/7 | I2S/FS0  | GCLK_IO5 |
 +------------+------------------+--------+-----------------+--------+-----+-----+-----+-----+---------+---------+--------+--------+----------+----------+
 */
  { PORTA, 22, PIO_DIGITAL, (PIN_ATTR_DIGITAL|PIN_ATTR_PWM|PIN_ATTR_TIMER    ), No_ADC_Channel, PWM4_CH0,   TC4_CH0,      EXTERNAL_INT_6    },
  { PORTA, 23, PIO_DIGITAL, (PIN_ATTR_DIGITAL|PIN_ATTR_PWM|PIN_ATTR_TIMER    ), No_ADC_Channel, PWM4_CH1,   TC4_CH1,      EXTERNAL_INT_7    },
  { PORTA, 10, PIO_DIGITAL, (PIN_ATTR_DIGITAL|PIN_ATTR_PWM|PIN_ATTR_TIMER    ), ADC_Channel18,  PWM1_CH0,   TCC1_CH0,     EXTERNAL_INT_NONE },
  { PORTA, 11, PIO_DIGITAL, (PIN_ATTR_DIGITAL|PIN_ATTR_PWM|PIN_ATTR_TIMER    ), ADC_Channel19,  PWM1_CH1,   TCC1_CH1,     EXTERNAL_INT_NONE },
  { PORTB, 10, PIO_DIGITAL, (PIN_ATTR_DIGITAL|PIN_ATTR_PWM|PIN_ATTR_TIMER    ), No_ADC_Channel, PWM5_CH0,   TC5_CH0,      EXTERNAL_INT_10   },
  { PORTB, 11, PIO_DIGITAL, (PIN_ATTR_DIGITAL|PIN_ATTR_PWM|PIN_ATTR_TIMER    ), No_ADC_Channel, PWM5_CH1,   TC5_CH1,      EXTERNAL_INT_11   },
  { PORTA, 20, PIO_DIGITAL, (PIN_ATTR_DIGITAL|PIN_ATTR_PWM|PIN_ATTR_TIMER_ALT), No_ADC_Channel, PWM0_CH6,   TCC0_CH6,     EXTERNAL_INT_4    },
  { PORTA, 21, PIO_DIGITAL, (PIN_ATTR_DIGITAL|PIN_ATTR_PWM|PIN_ATTR_TIMER_ALT), No_ADC_Channel, PWM0_CH7,   TCC0_CH7,     EXTERNAL_INT_5    },
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

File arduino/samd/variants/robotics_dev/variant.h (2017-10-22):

/*
  Copyright (c) 2014-2015 Arduino LLC.  All right reserved.

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
  You should have received a copy of the GNU Lesser General Public
  License along with this library; if not, write to the Free Software
  Foundation, Inc., 51 Franklin St, Fifth Floor, Boston, MA  02110-1301  USA
*/

#pragma once

// The definitions here needs a SAMD core >=1.6.10
#define ARDUINO_SAMD_VARIANT_COMPLIANCE 10610

#include <WVariant.h>

// General definitions
// -------------------

// Frequency of the board main oscillator
#define VARIANT_MAINOSC (32768ul)

// Master clock frequency
#define VARIANT_MCK     (48000000ul)

// Pins
// ----

// Robotics J1...J7
#define RJ1   (15u) // PA02: D15 / A0
#define RJ2   (25u) // PA03: D25 / A7/AREF
#define RJ3   (18u) // PA04: D18 / A3
#define RJ4   (19u) // PA05: D19 / A4
#define RJ5   (20u) // PA06: D20 / A5
#define RJ6   (21u) // PA07: D21 / A6
#define RJ7   (16u) // PB02: D16 / A1
// Robotics M1...M4
#define RM1A   (7u) // PA21: D7
#define RM1B   (6u) // PA20: D6
#define RM2A   (1u) // PA23: D1
#define RM2B   (0u) // PA22: D0
#define RM3A   (3u) // PA11: D3
#define RM3B   (2u) // PA10: D2
#define RM4A   (5u) // PB11: D5
#define RM4B   (4u) // PB10: D4
#define RVBB  (17u) // PB3: D17 / A2
// Robotics S1
#define RS1   (36u) // PA31 / SWDIO (Dev-Edition: PA30 / SWCLK)

// Number of pins defined in PinDescription array
#define PINS_COUNT           (26u) // 26
#define NUM_DIGITAL_PINS     (22u) // 22
#define NUM_ANALOG_INPUTS    (7u)  // 7
#define NUM_ANALOG_OUTPUTS   (1u)  // 1
#define analogInputToDigitalPin(p)  ((p < 7u) ? (p) + 15u : -1)

// Low-level pin register query macros
// -----------------------------------
#define digitalPinToPort(P)      (&(PORT->Group[g_APinDescription[P].ulPort]))
#define digitalPinToBitMask(P)   (1 << g_APinDescription[P].ulPin)
//#define analogInPinToBit(P)    ()
#define portOutputRegister(port) (&(port->OUT.reg))
#define portInputRegister(port)  (&(port->IN.reg))
#define portModeRegister(port)   (&(port->DIR.reg))
#define digitalPinHasPWM(P)      (g_APinDescription[P].ulPWMChannel != NOT_ON_PWM || g_APinDescription[P].ulTCChannel != NOT_ON_TIMER)

/*
 * digitalPinToTimer(..) is AVR-specific and is not defined for SAMD
 * architecture. If you need to check if a pin supports PWM you must
 * use digitalPinHasPWM(..).
 *
 * https://github.com/arduino/Arduino/issues/1833
 */
// #define digitalPinToTimer(P)

// LEDs
// ----
#define PIN_LED     (37u) // PA30 / SWCLK (Dev-Edition: PA31 / SWDIO)
#define LED_BUILTIN PIN_LED

// Analog pins
// -----------
#define PIN_A0   (15u)
#define PIN_A1   (16u)
#define PIN_A2   (17u)
#define PIN_A3   (18u)
#define PIN_A4   (19u)
#define PIN_A5   (20u)
#define PIN_A6   (21u)
#define PIN_A7   (25u)
#define PIN_DAC0 (15u)

static const uint8_t A0   = PIN_A0;
static const uint8_t A1   = PIN_A1;
static const uint8_t A2   = PIN_A2;
static const uint8_t A3   = PIN_A3;
static const uint8_t A4   = PIN_A4;
static const uint8_t A5   = PIN_A5;
static const uint8_t A6   = PIN_A6;
static const uint8_t A7   = PIN_A7;
static const uint8_t DAC0 = PIN_DAC0;
#define ADC_RESOLUTION 12

// SPI Interfaces
// --------------
#define SPI_INTERFACES_COUNT 2

// SPI
#define PIN_SPI_MISO  (10u)
#define PIN_SPI_MOSI  (8u)
#define PIN_SPI_SCK   (9u)
#define PIN_SPI_SS    (24u)
#define PERIPH_SPI    sercom1
#define PAD_SPI_TX    SPI_PAD_0_SCK_1
#define PAD_SPI_RX    SERCOM_RX_PAD_3
static const uint8_t SS   = PIN_SPI_SS;   // SPI Slave SS not used. Set here only for reference.
static const uint8_t MOSI = PIN_SPI_MOSI;
static const uint8_t MISO = PIN_SPI_MISO;
static const uint8_t SCK  = PIN_SPI_SCK;

// SPI1: Connected to WINC1501B
#define PIN_SPI1_MISO (29u)
#define PIN_SPI1_MOSI (26u)
#define PIN_SPI1_SCK  (27u)
#define PIN_SPI1_SS   (28u)
#define PERIPH_SPI1   sercom2
#define PAD_SPI1_TX   SPI_PAD_0_SCK_1
#define PAD_SPI1_RX   SERCOM_RX_PAD_3
static const uint8_t SS1   = PIN_SPI1_SS;
static const uint8_t MOSI1 = PIN_SPI1_MOSI;
static const uint8_t MISO1 = PIN_SPI1_MISO;
static const uint8_t SCK1  = PIN_SPI1_SCK;

// Wire Interfaces
// ---------------
#define WIRE_INTERFACES_COUNT 1

// Wire
#define PIN_WIRE_SDA        (11u)
#define PIN_WIRE_SCL        (12u)
#define PERIPH_WIRE         sercom0
#define WIRE_IT_HANDLER     SERCOM0_Handler
static const uint8_t SDA = PIN_WIRE_SDA;
static const uint8_t SCL = PIN_WIRE_SCL;

// USB
// ---
#define PIN_USB_DM          (22u)
#define PIN_USB_DP          (23u)
#define PIN_USB_HOST_ENABLE (-1)

// Needed for WINC1501B (WiFi101) library
// --------------------------------------
#define WINC1501_RESET_PIN   (30u)
#define WINC1501_CHIP_EN_PIN (31u)
#define WINC1501_INTN_PIN    (33u)
#define WINC1501_SPI         SPI1
#define WINC1501_SPI_CS_PIN  PIN_SPI1_SS


// Serial ports
// ------------
#ifdef __cplusplus
#include "SERCOM.h"
#include "Uart.h"

// Instances of SERCOM
extern SERCOM sercom0;
extern SERCOM sercom1;
extern SERCOM sercom2;
extern SERCOM sercom3;
extern SERCOM sercom4;
extern SERCOM sercom5;

// Serial1
extern Uart Serial1;
#define PIN_SERIAL1_RX (13u)
#define PIN_SERIAL1_TX (14u)
#define PAD_SERIAL1_TX (UART_TX_PAD_2)
#define PAD_SERIAL1_RX (SERCOM_RX_PAD_3)
#endif // __cplusplus

// These serial port names are intended to allow libraries and architecture-neutral
// sketches to automatically default to the correct port name for a particular type
// of use.  For example, a GPS module would normally connect to SERIAL_PORT_HARDWARE_OPEN,
// the first hardware serial port whose RX/TX pins are not dedicated to another use.
//
// SERIAL_PORT_MONITOR        Port which normally prints to the Arduino Serial Monitor
//
// SERIAL_PORT_USBVIRTUAL     Port which is USB virtual serial
//
// SERIAL_PORT_LINUXBRIDGE    Port which connects to a Linux system via Bridge library
//
// SERIAL_PORT_HARDWARE       Hardware serial port, physical RX & TX pins.
//
// SERIAL_PORT_HARDWARE_OPEN  Hardware serial ports which are open for use.  Their RX & TX
//                            pins are NOT connected to anything by default.
#define SERIAL_PORT_USBVIRTUAL      SerialUSB
#define SERIAL_PORT_MONITOR         SerialUSB
#define SERIAL_PORT_HARDWARE        Serial1
#define SERIAL_PORT_HARDWARE_OPEN   Serial1

// Alias Serial to SerialUSB
#define Serial                      SerialUSB

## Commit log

2017-10-22 updated pin info
2017-12-02 updated schematics
    [Eitech-Robotics_v10.brd, Eitech-Robotics_v10.sch, Eitech-Robotics_v10dev.brd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]
2017-12-02 updated BSP and WiFi101 lib
    [arduino_zero.cfg]
2018-03-02 updated bootloader and bsp
    [robotics.cfg, robotics.cfg.cfg]
2019-02-11 added rev 1.1
    [Eitech-Robotics_v11.brd, Eitech-Robotics_v11.sch]
